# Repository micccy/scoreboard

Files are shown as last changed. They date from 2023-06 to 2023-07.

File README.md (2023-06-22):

# Mictronic5677 scoreboard, a basic electronic scoreboard project

**Standard disclaimer:** _this is some project of mine that was created to tackle some very specific need and might not work as well elsewhere. However, it may still be useful to someone, so here it is._

**Description:** The mictronic5677 scoreboard project was born as a way to revive an old broken rusty electronic scoreboard chassis we found laying around. All of the control circuitry has been redone from scratch, it now implements an ATmega328P running at 4MHz and programmed in assembler to ensure exact timings. Every development choice has been taken as a direct response to precise needs, to ensure max reliability and most importantly to keep it cheap and made from easy to source components. A time signal radio receiver has been added to keep the time-of-day clock accurate 

**Status:** _Kinda functional (basic operation only)- incomplete documentation (no schematics available yet)_

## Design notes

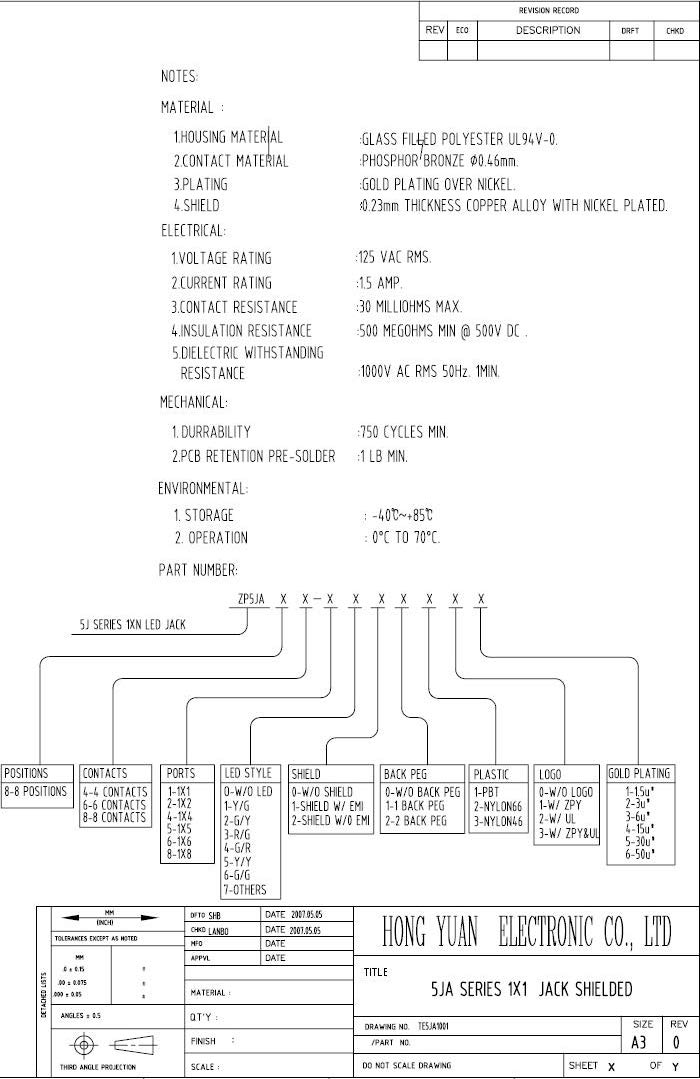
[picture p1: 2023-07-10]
doc/8P8C_5JA.jpg

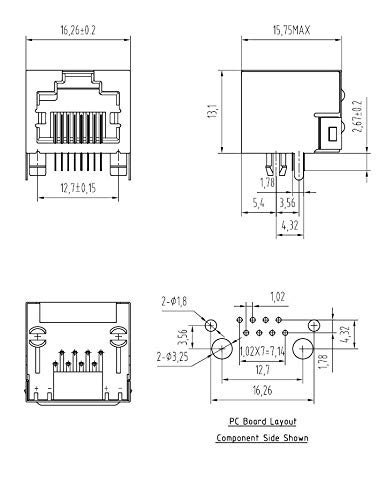
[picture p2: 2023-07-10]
doc/8P8C_5JA_dim.jpg

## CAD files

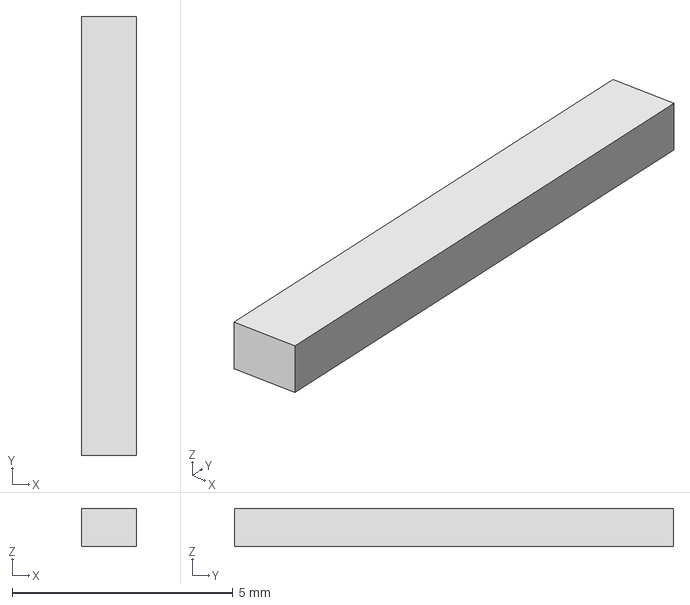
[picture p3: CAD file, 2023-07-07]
pcb/Trans_On Semiconductor_D45H8G/eec.models/On_Semiconductor_-_D45H8G.step
1.25 x 9.95 x 0.87 mm

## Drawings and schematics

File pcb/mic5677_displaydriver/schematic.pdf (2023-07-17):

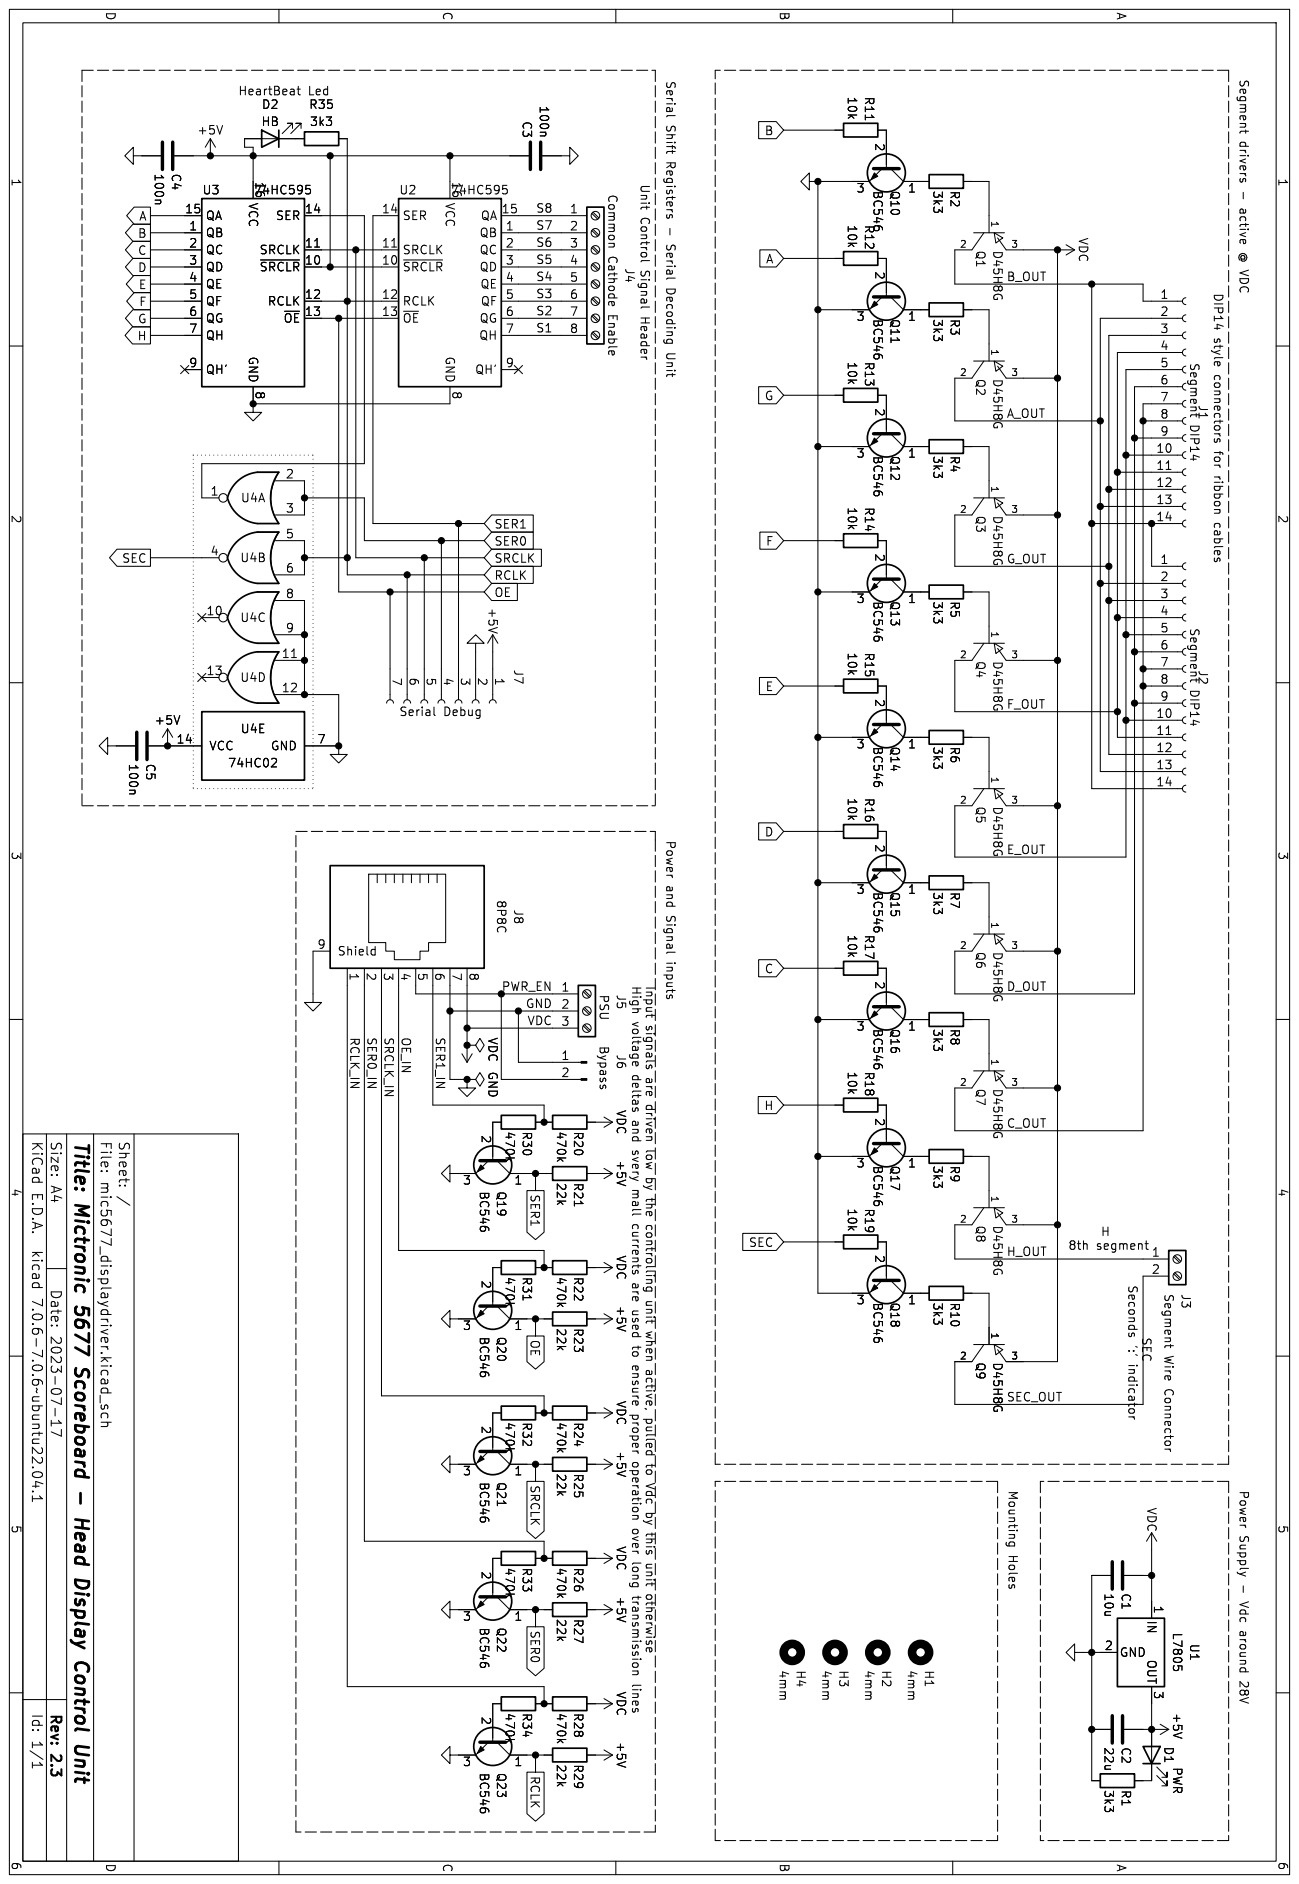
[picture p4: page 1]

Serial Shift Registers - Serial Decoding Unit HeartBeat Led Power and Signal inputs SEC

Segment drivers - active @ VDC

DIP14 style connectors for ribbon cables Mounting Holes U3 74HC595 QB

Input signals are driven low by the controlling unit when active, pulled to Vdc by this unit otherwise High voltage deltas and svery mall currents are used to ensure proper operation over long transmission lines Unit Control Signal Header H 8th segment

Id: 1/1 Title: Mictronic 5677 Scoreboard - Head Display Control Unit File: mic5677_displaydriver.kicad_sch Sheet: / 470k R20

Date: 2023-07-17 KiCad E.D.A. kicad 7.0.6-7.0.6~ubuntu22.04.1 Rev: 2.3 Size: A4

Seconds ':' indicator Power Supply - Vdc around 28V

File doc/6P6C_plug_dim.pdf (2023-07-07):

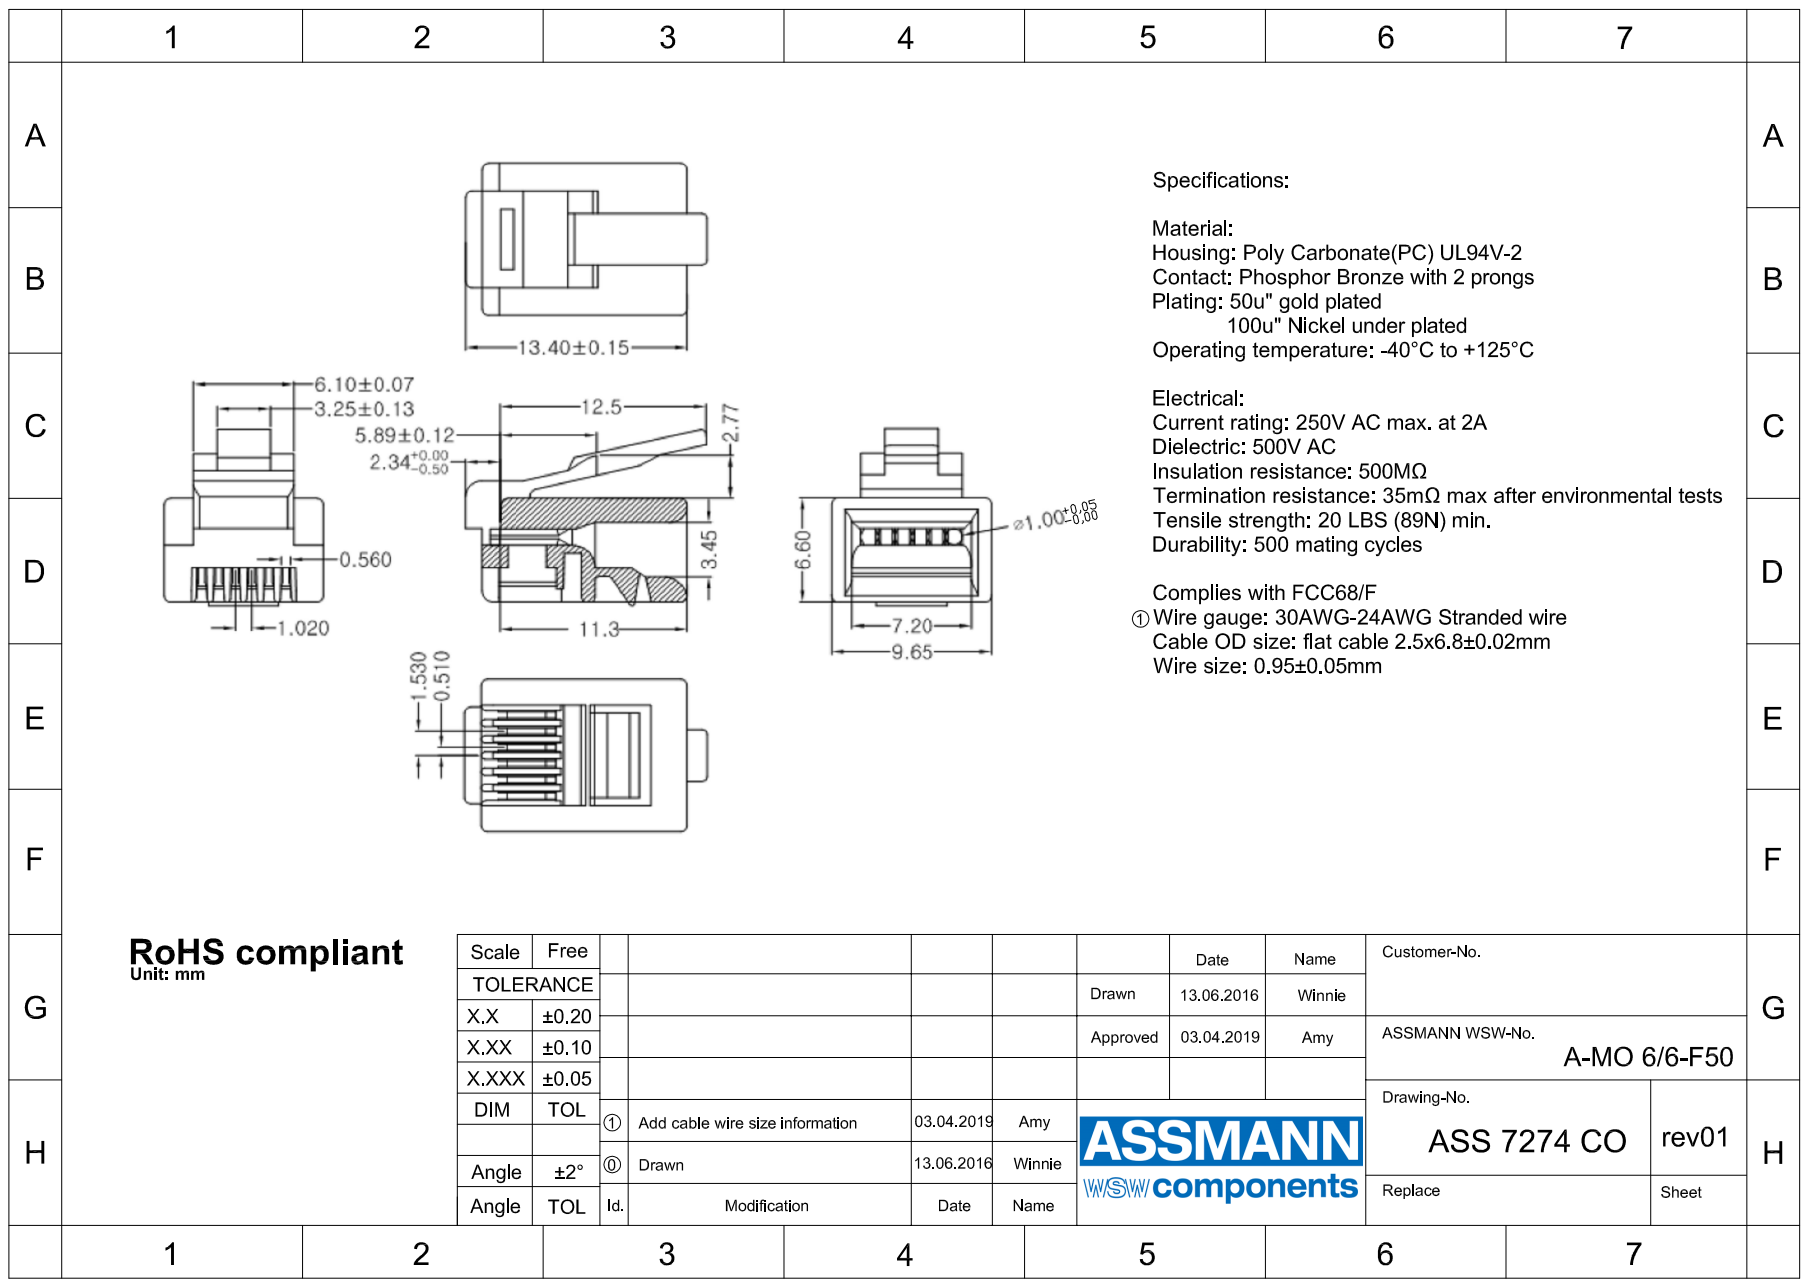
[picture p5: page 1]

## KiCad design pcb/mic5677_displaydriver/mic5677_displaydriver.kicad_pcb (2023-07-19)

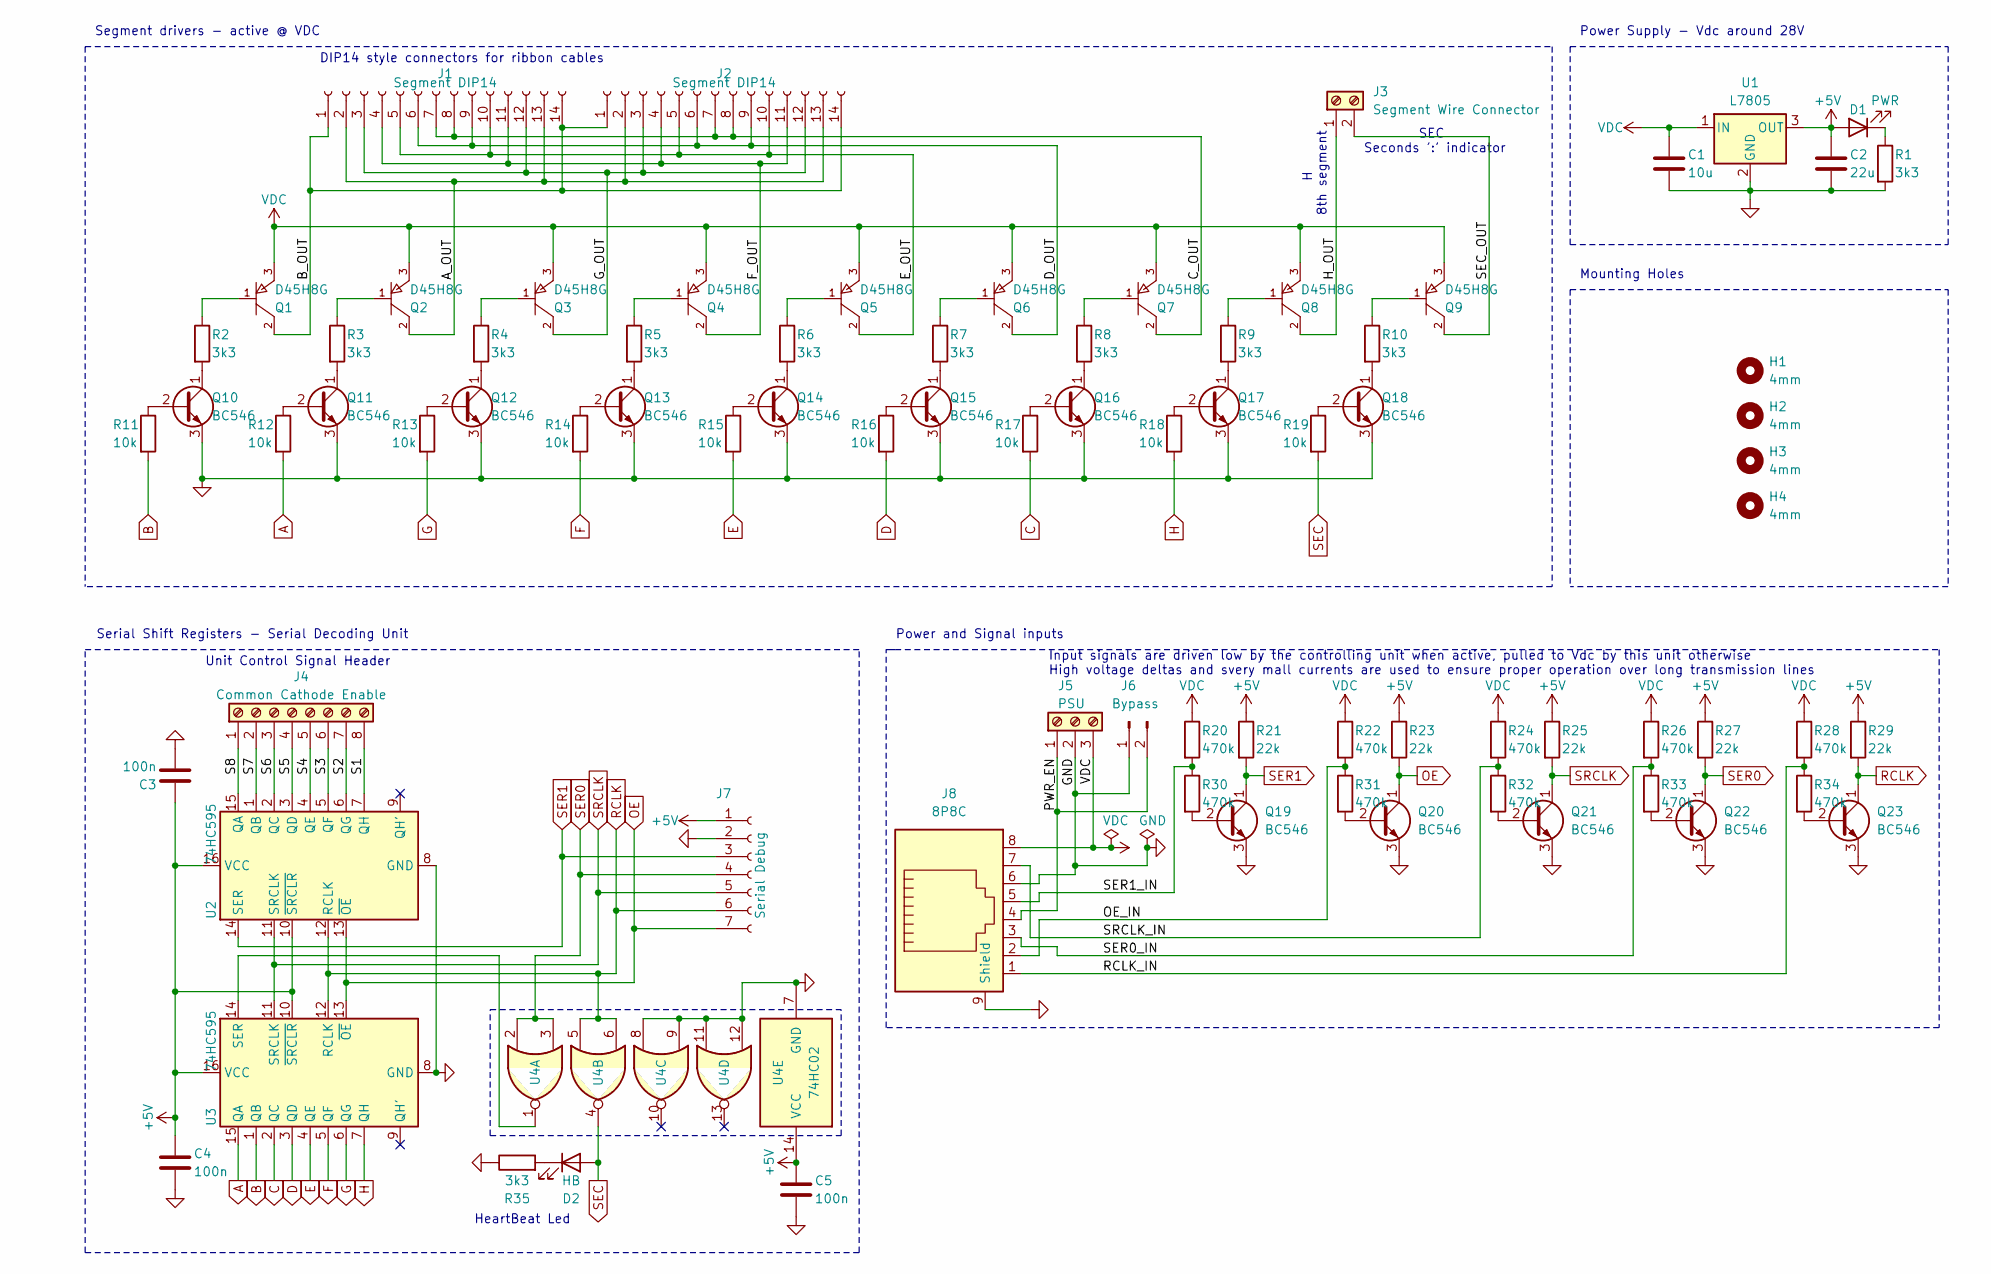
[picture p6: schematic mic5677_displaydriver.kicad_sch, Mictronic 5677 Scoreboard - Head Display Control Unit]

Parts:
C1: 10u; C_Disc_D3.8mm_W2.6mm_P2.50mm
C2: 22u; C_Disc_D3.8mm_W2.6mm_P2.50mm
C3, C4, C5: 100n; C_Disc_D3.8mm_W2.6mm_P2.50mm
D1: PWR; LED_D3.0mm
D2: HB; LED_D3.0mm
H1, H2, H3, H4: 4mm; MountingHole_4mm
J1, J2: Segment DIP14; DIP-14_W7.62mm_Socket
J3: Segment Wire Connector; TerminalBlock_bornier-2_P5.08mm
J4: Common Cathode Enable; TerminalBlock_RND_205-00238_1x08_P5.08mm_Horizontal
J5: PSU; TerminalBlock_bornier-3_P5.08mm
J6: Bypass; PinHeader_1x02_P2.54mm_Vertical
J7: Serial Debug; PinSocket_1x07_P2.54mm_Vertical
J8: 8P8C; RJ45_Amphenol_54602-x08_Horizontal
Q1, Q2, Q3, Q4, Q5, Q6, Q7, Q8, Q9: D45H8G; On_Semiconductor-D45H8G-Manufacturer_Recommended
Q10, Q11, Q12, Q13, Q14, Q15, Q16, Q17, Q18, Q19, Q20, Q21, Q22, Q23: BC546; TO-92_Inline
R1, R2, R3, R4, R5, R6, R7, R8, R9, R10, R35: 3k3; R_Axial_DIN0204_L3.6mm_D1.6mm_P7.62mm_Horizontal
R11, R12, R13, R14, R15, R16, R17, R18, R19: 10k; R_Axial_DIN0204_L3.6mm_D1.6mm_P7.62mm_Horizontal
R20, R22, R24, R26, R28, R30, R31, R32, R33, R34: 470k; R_Axial_DIN0204_L3.6mm_D1.6mm_P7.62mm_Horizontal
R21, R23, R25, R27, R29: 22k; R_Axial_DIN0204_L3.6mm_D1.6mm_P7.62mm_Horizontal
U1: L7805; TO-220-3_Vertical
U2, U3: 74HC595; DIP-16_W7.62mm_Socket
U4: 74HC02; DIP-14_W7.62mm_Socket

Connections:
+5V: C2.1, C3.1, C4.1, C5.1, D1.2 (A), J7.1, R21.1, R23.1, R25.1, R27.1, R29.1, U1.3 (OUT), U2.10 (~SRCLR), U2.16 (VCC), U3.10 (~SRCLR), U3.16 (VCC), U4.14 (VCC)
/A_OUT: J1.2, J1.13, J2.2, J2.13, Q2.2 (C)
/B_OUT: J1.1, J1.14, J2.1, J2.14, Q1.2 (C)
/C_OUT: J1.7, J1.8, J2.7, J2.8, Q7.2 (C)
/D_OUT: J1.6, J1.9, J2.6, J2.9, Q6.2 (C)
/E_OUT: J1.5, J1.10, J2.5, J2.10, Q5.2 (C)
/F_OUT: J1.4, J1.11, J2.4, J2.11, Q4.2 (C)
/G_OUT: J1.3, J1.12, J2.3, J2.12, Q3.2 (C)
/H_OUT: J3.1, Q8.2 (C)
/OE_IN: J8.2, R22.2, R31.1
/PWR_EN: J5.1, J6.2, J8.4
/RCLK_IN: J8.1, R28.2, R34.1
/S1: J4.8, U2.7 (QH)
/S2: J4.7, U2.6 (QG)
/S3: J4.6, U2.5 (QF)
/S4: J4.5, U2.4 (QE)
/S5: J4.4, U2.3 (QD)
/S6: J4.3, U2.2 (QC)
/S7: J4.2, U2.1 (QB)
/S8: J4.1, U2.15 (QA)
/SEC_OUT: J3.2, Q9.2 (C)
/SER0_IN: J8.3, R26.2, R33.1
/SER1_IN: J8.5, R20.2, R30.1
/SRCLK_IN: J8.7, R24.2, R32.1
A: R12.2, U3.15 (QA)
B: R11.2, U3.1 (QB)
C: R17.2, U3.2 (QC)
D: R16.2, U3.3 (QD)
E: R15.2, U3.4 (QE)
F: R14.2, U3.5 (QF)
G: R13.2, U3.6 (QG)
GND: C1.2, C2.2, C3.2, C4.2, C5.2, J5.2, J6.1, J7.2, J8.6, J8.9 (Shield), Q10.3 (E), Q11.3 (E), Q12.3 (E), Q13.3 (E), Q14.3 (E), Q15.3 (E), Q16.3 (E), Q17.3 (E), Q18.3 (E), Q19.3 (E), Q20.3 (E), Q21.3 (E), Q22.3 (E), Q23.3 (E), R1.2, R35.1, U1.2 (GND), U2.8 (GND), U3.8 (GND), U4.7 (GND), U4.8, U4.9, U4.11, U4.12
H: R18.2, U3.7 (QH)
unnamed: D1.1 (K), R1.1
unnamed: D2.1 (K), R35.2
unnamed: Q1.1 (B), R2.1
unnamed: Q2.1 (B), R3.1
unnamed: Q3.1 (B), R4.1
unnamed: Q4.1 (B), R5.1
unnamed: Q5.1 (B), R6.1
unnamed: Q6.1 (B), R7.1
unnamed: Q7.1 (B), R8.1
unnamed: Q8.1 (B), R9.1
unnamed: Q9.1 (B), R10.1
unnamed: Q10.2 (B), R11.1
unnamed: Q10.1 (C), R2.2
unnamed: Q11.2 (B), R12.1
unnamed: Q11.1 (C), R3.2
unnamed: Q12.2 (B), R13.1
unnamed: Q12.1 (C), R4.2
unnamed: Q13.2 (B), R14.1
unnamed: Q13.1 (C), R5.2
unnamed: Q14.2 (B), R15.1
unnamed: Q14.1 (C), R6.2
unnamed: Q15.2 (B), R16.1
unnamed: Q15.1 (C), R7.2
unnamed: Q16.2 (B), R17.1
unnamed: Q16.1 (C), R8.2
unnamed: Q17.2 (B), R18.1
unnamed: Q17.1 (C), R9.2
unnamed: Q18.2 (B), R19.1
unnamed: Q18.1 (C), R10.2
unnamed: Q19.2 (B), R30.2
unnamed: Q20.2 (B), R31.2
unnamed: Q21.2 (B), R32.2
unnamed: Q22.2 (B), R33.2
unnamed: Q23.2 (B), R34.2
unnamed: U3.14 (SER), U4.1
OE: J7.7, Q20.1 (C), R23.2, U2.13 (~OE), U3.13 (~OE)
RCLK: J7.6, Q23.1 (C), R29.2, U2.12 (RCLK), U3.12 (RCLK), U4.5, U4.6
SEC: D2.2 (A), R19.2, U4.4
SER0: J7.4, Q22.1 (C), R27.2, U4.2, U4.3
SER1: J7.3, Q19.1 (C), R21.2, U2.14 (SER)
SRCLK: J7.5, Q21.1 (C), R25.2, U2.11 (SRCLK), U3.11 (SRCLK)
VDC: C1.1, J5.3, J8.8, Q1.3 (E), Q2.3 (E), Q3.3 (E), Q4.3 (E), Q5.3 (E), Q6.3 (E), Q7.3 (E), Q8.3 (E), Q9.3 (E), R20.1, R22.1, R24.1, R26.1, R28.1, U1.1 (IN)

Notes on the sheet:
Unit Control Signal Header
H 8th segment
Power and Signal inputs
Input signals are driven low by the controlling unit when active, pulled to Vdc by this unit otherwise High voltage deltas and svery mall currents are used to ensure proper operation over long transmission lines
SEC Seconds ':' indicator
DIP14 style connectors for ribbon cables
Mounting Holes
Serial Shift Registers - Serial Decoding Unit
Segment drivers - active @ VDC
Power Supply - Vdc around 28V
HeartBeat Led

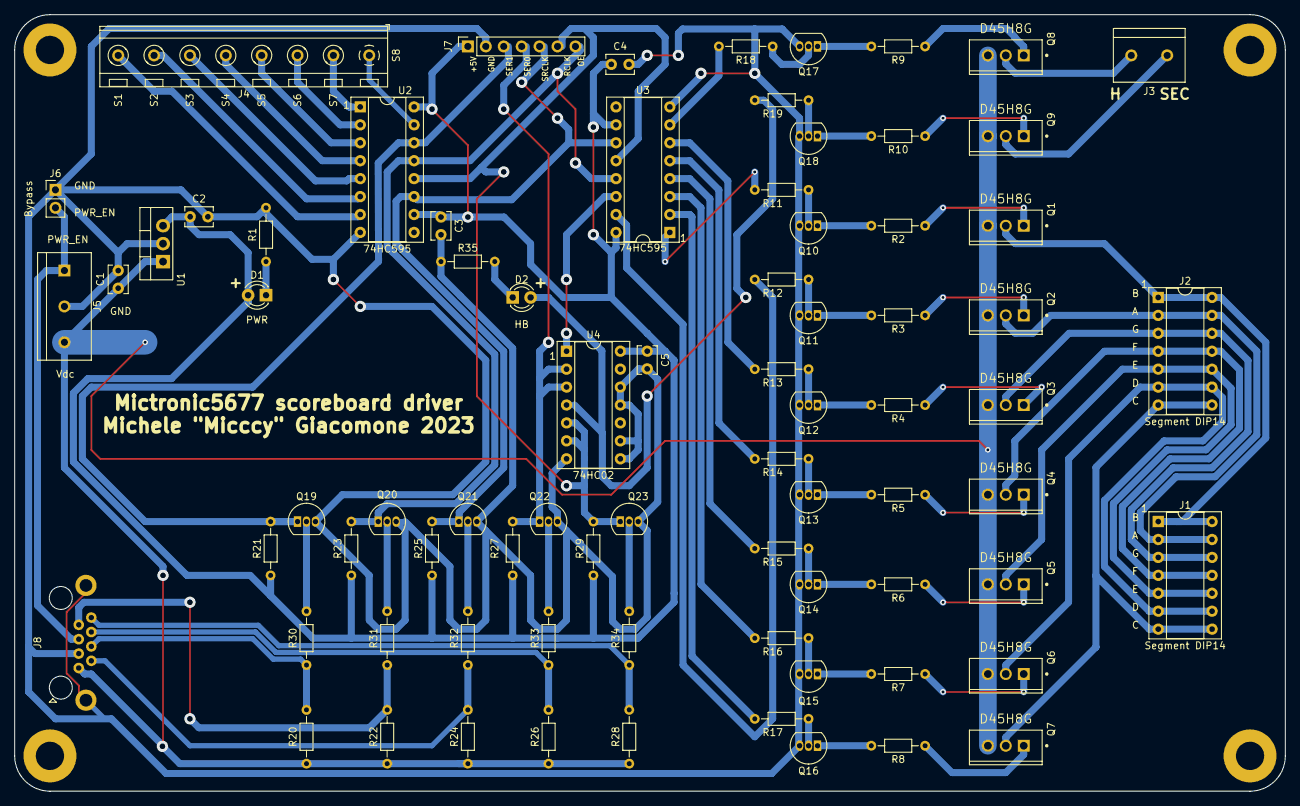
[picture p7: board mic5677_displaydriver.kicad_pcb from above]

Board: 2 copper layers, 180.0 x 110.0 mm, 81 parts (0 on the bottom side), 75 nets.

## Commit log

2023-06-23 Added watchdog support and power reduction
2023-07-07 added display driver pcb project
    [On_Semiconductor_-_D45H8G.step, mic5677_displaydriver.kicad_pcb, mic5677_displaydriver.kicad_sch]
2023-07-07 Added some component documentation
    [mic5677_displaydriver.kicad_sch]
2023-07-08 Updated display pcb
    [mic5677_displaydriver.kicad_pcb, mic5677_displaydriver.kicad_sch]
2023-07-09 Improved display driver pcb
    [mic5677_displaydriver.kicad_pcb, mic5677_displaydriver.kicad_sch]
2023-07-10 Finished display driver pcb
    [mic5677_displaydriver.kicad_pcb, mic5677_displaydriver.kicad_sch]
2023-07-10 Added some silkscreen on pcb and changed io style
    [mic5677_displaydriver.kicad_pcb, mic5677_displaydriver.kicad_sch]
2023-07-11 Made display driver pcb slightly worse but easier to manufacture
    [mic5677_displaydriver.kicad_pcb]
2023-07-13 Added back fill zones to display driver pcb
    [mic5677_displaydriver.kicad_pcb]
2023-07-13 Added back printable file
    [mic5677_displaydriver.kicad_pcb]
2023-07-13 Made display driver pcb work both with and without filled fill zones
    [mic5677_displaydriver.kicad_pcb, mic5677_displaydriver.kicad_sch]
2023-07-13 MadeAdded gnd pads to port on d.driver pcb
    [mic5677_displaydriver.kicad_pcb]
2023-07-13 Made ddriver pcb project pretty
    [mic5677_displaydriver.kicad_pcb]
2023-07-13 Added ddriver front printable document
    [mic5677_displaydriver.kicad_pcb]
2023-07-16 Added power pins on serial debug port
    [mic5677_displaydriver.kicad_pcb, mic5677_displaydriver.kicad_sch]
2023-07-17 Updated ddriver to v2.3
    [mic5677_displaydriver.kicad_pcb, mic5677_displaydriver.kicad_sch]
2023-07-17 fixed ddriver front pdf
    [mic5677_displaydriver.kicad_pcb]
2023-07-19 Moved ddriver HB led, adopted better 8p8c pinout, improved fill zones
    [mic5677_displaydriver.kicad_pcb, mic5677_displaydriver.kicad_sch]
